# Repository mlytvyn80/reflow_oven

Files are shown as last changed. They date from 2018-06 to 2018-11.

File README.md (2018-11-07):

# Reflow owen

Description

## Getting Started

The firmware can be compiled using make utility. 
```
make all
```

Some more make targets are supported, namely *all, clean, coff extcodd program, debug.*
Please consult the Makefile for usage details.

### Prerequisites

In order to compile the HEX-file you need to install the AVR toolchain. 

In Ubuntu/Debian Linux this can be done using the following command:
```
sudo apt-get install gcc-avr
```

To be able to flash the firmware you will need a driver AVR MCU programmer (for example [usbasp](https://www.fischl.de/usbasp/) ) and the 
driving program like [avrdude](https://www.nongnu.org/avrdude/).

avrdude is included in the most of Linux distribution. In Ubuntu/Debian you can issue:
```
sudo apt-get install avrdude
```

### Flashing the firmware
Connect the ISP head with your AVR MCU programmer, programmer to PC and flash the compiled HEX-file:
```
avrdude -c usbasp -p m32u4 -U flash:w:ovencon.hex
```

In order to configure MCU to work with external oscillator (in our case 16MHz quartz), it is necessary to
setup fuse bits.

It can be done by command:
```
avrdude -c usbasp -p m32u4 -U hfuse:w:0xdd:m -U lfuse:w:0xde:m -U efuse:w:0xcf:m
```

## Built With

* [GNU AVR toolchain](http://www.dropwizard.io/1.0.2/docs/) - The web framework used
* [avrdude](https://maven.apache.org/) - Dependency Management
* [usbasp](https://www.fischl.de/usbasp/) - AVR MCU programmer

## Authors

* **Daniel Strother** - *Initial work* - [danstrother.com](https://danstrother.com/2011/01/15/reflow-oven-controller/)
* **Oleg Artamonov** - *PCB Design*  - [olegart.ru](http://olegart.ru/wordpress/reflow-soldering/)
* **Mykhailo Lytvyn** - Collect all necessary build-related information together.

## License

The code is distributed "AS IS" under original License by Dan Strother (see header comments in source code).

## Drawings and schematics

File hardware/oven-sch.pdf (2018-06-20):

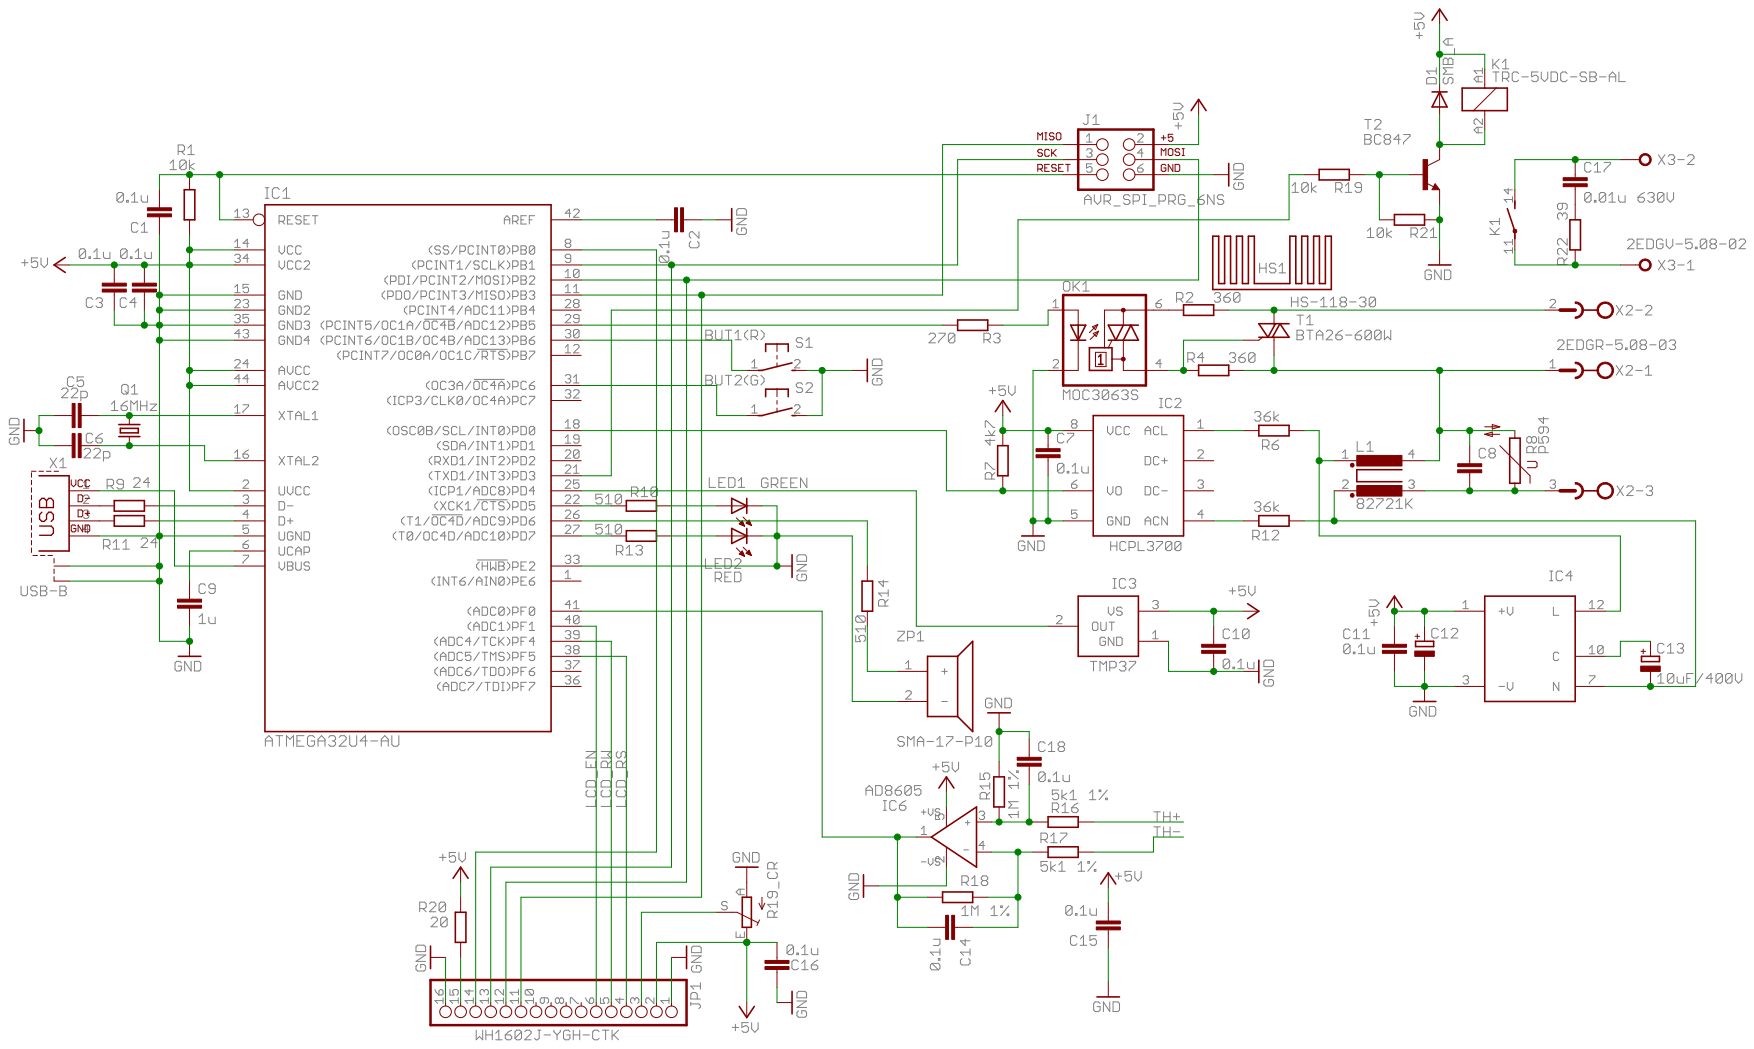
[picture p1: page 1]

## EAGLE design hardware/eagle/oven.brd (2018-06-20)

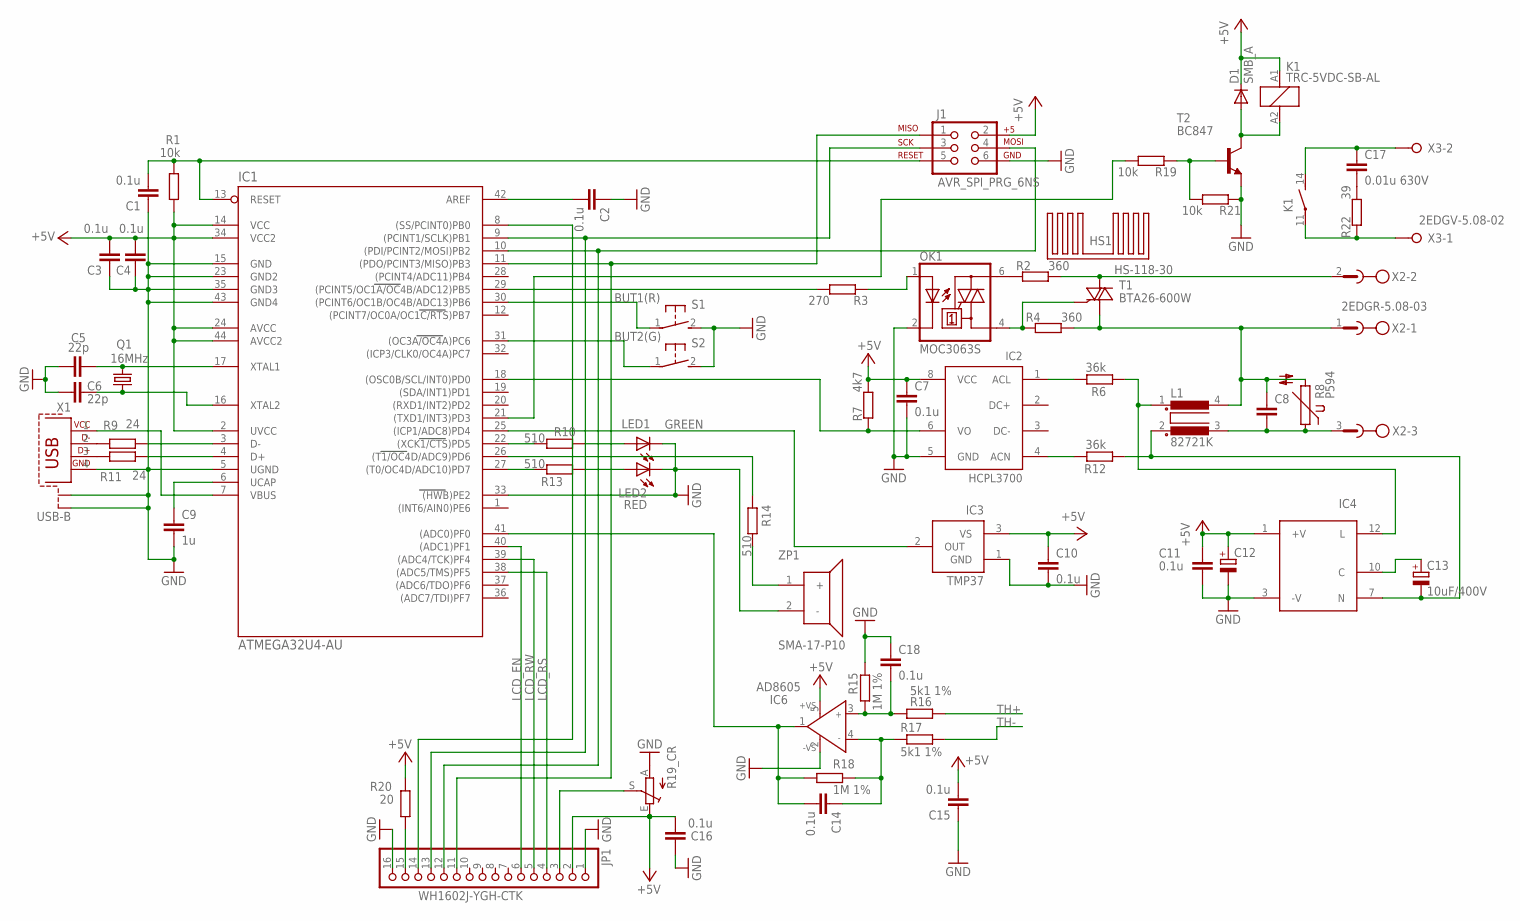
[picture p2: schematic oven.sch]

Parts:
C1, C2, C3, C4, C7, C10, C11, C14, C15, C16, C18: 0.1u; C0805R
C5, C6: 22p; C0805R
C8: C-EU102-054X133; C102-054X133
C9: 1u; C0805R
C12: CPOL-EUE3.5-8; E3,5-8
C13: 10uF/400V; E5-10,5
C17: 0.01u 630V; C102-043X133
D1: SMB_A; DO-214AC
HS1: HS-118-30; HS-118
IC1: ATMEGA32U4-AU; TQFP44
IC2: HCPL3700; DIL08
IC3: TMP37; TO92
IC4: PPM2.5-S12-05ELF; SIP12
IC6: AD8605; SOT23-5
J1: AVR_SPI_PRG_6NS; 2X3-NS
JP1: WH1602J-YGH-CTK; 1X16
K1: TRC-5VDC-SB-AL; TRC
L1: 82721K
LED1: GREEN; LED3MM
LED2: RED; LED3MM
OK1: MOC3063S; DIL6-SMD
Q1: 16MHz; HC49/S
R1, R19, R21: 10k; R0805R
R2, R4: 360; R2512
R3: 270; R0805R
R6, R12: 36k; R1206R
R7: 4k7; R0805R
R8: P594
R9, R11: 24; R0805R
R10, R13, R14: 510; R0805R
R15, R18: 1M 1%; R0805R
R16, R17: 5k1 1%; R0805R
R19_CR: TRIM_EU-CA6V; CA6V
R20: 20; R0805R
R22: 39; 0207/5V
S1, S2: 31-XX; B3F-31XX
T1: BTA26-600W; TOP3S-1
T2: BC847; SOT23
X1: USB-B; PN61729-S
X2: 2EDGR-5.08-03; W232-3
X3: 2EDGV-5.08-02; W237-132
ZP1: SMA-17-P10; SMA-17

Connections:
+5V: C3.2, C4.2, C7.1, C10.1, C11.1, C12.+, C15.2, C16.2, D1.C, IC1.2 (UVCC), IC1.14 (VCC), IC1.24 (AVCC), IC1.34 (VCC2), IC1.44 (AVCC2), IC2.8 (VCC), IC3.3 (VS), IC4.1 (+V), IC6.5 (+VS), J1.2, JP1.2, K1.A1 (1), R1.1, R7.2, R19_CR.E, R20.1
BUT1(R): IC1.30 ((PCINT6/OC1B/OC4B/ADC13)PB6), S1.1
BUT2(G): IC1.31 ((OC3A/OC4A)PC6), S2.1
GND: C1.1, C2.1, C3.1, C4.1, C5.1, C6.1, C7.2, C9.2, C10.2, C11.2, C12.-, C15.1, C16.1, C18.1, IC1.5 (UGND), IC1.15 (GND), IC1.23 (GND2), IC1.33 ((HWB)PE2), IC1.35 (GND3), IC1.43 (GND4), IC2.5 (GND), IC3.1 (GND), IC4.3 (-V), IC6.2 (-VS), J1.6, JP1.1, JP1.16, LED1.K (C), LED2.K (C), OK1.2 (C), R15.2, R19_CR.A, R21.1, S1.2 (S), S2.2 (S), T2.2 (E), X1.4, X1.S1, X1.S2, ZP1.2 (-)
LCD_D4: IC1.11 ((PDO/PCINT3/MISO)PB3), J1.1, JP1.11
LCD_D5: IC1.10 ((PDI/PCINT2/MOSI)PB2), J1.4, JP1.12
LCD_D6: IC1.9 ((PCINT1/SCLK)PB1), J1.3, JP1.13
LCD_D7: IC1.8 ((SS/PCINT0)PB0), JP1.14
LCD_EN: IC1.40 ((ADC1)PF1), JP1.6
LCD_RS: IC1.38 ((ADC5/TMS)PF5), JP1.4
LCD_RW: IC1.39 ((ADC4/TCK)PF4), JP1.5
unnamed: C9.1, IC1.6 (UCAP)
unnamed: R9.1, X1.2
unnamed: R11.1, X1.3
unnamed: IC1.3 (D-), R9.2
unnamed: IC1.4 (D+), R11.2
unnamed: IC1.7 (VBUS), X1.1
unnamed: IC1.18 ((OSC0B/SCL/INT0)PD0), IC2.6 (VO), R7.1
unnamed: C5.2, IC1.17 (XTAL1), Q1.2
unnamed: C6.2, IC1.16 (XTAL2), Q1.1
unnamed: IC1.29 ((PCINT5/OC1A/OC4B/ADC12)PB5), R3.2
unnamed: C1.2, IC1.13 (RESET), J1.5, R1.2
unnamed: C2.2, IC1.42 (AREF)
unnamed: C17.2, R22.2
unnamed: OK1.1 (A), R3.1
unnamed: OK1.6 (A2), R2.1
unnamed: OK1.4 (A1), R4.1, T1.G
unnamed: R2.2, T1.A2, X2.2
unnamed: IC4.12 (L), L1.1, R6.1
unnamed: JP1.15, R20.2
unnamed: IC1.25 ((ICP1/ADC8)PD4), IC3.2 (OUT)
unnamed: IC2.4 (ACN), R12.2
unnamed: C14.2, IC1.41 ((ADC0)PF0), IC6.1 (OUT), R18.1
unnamed: C18.2, IC6.3 (IN+), R15.1, R16.1
unnamed: C14.1, IC6.4 (IN-), R17.1, R18.2
unnamed: IC2.1 (ACL), R6.2
unnamed: LED1.A, R10.1
unnamed: C13.+, IC4.10 (C)
unnamed: IC1.22 ((XCK1/CTS)PD5), R10.2
unnamed: IC1.26 ((T1/OC4D/ADC9)PD6), R14.1
unnamed: IC1.27 ((T0/OC4D/ADC10)PD7), R13.2
unnamed: LED2.A, R13.1
unnamed: C13.-, IC4.7 (N), L1.2 (3), R12.1
unnamed: C8.1, L1.4 (2), R4.2, R8.2, T1.A1, X2.1
unnamed: C8.2, L1.3 (4), R8.1, X2.3
unnamed: JP1.3, R19_CR.S
unnamed: D1.A, K1.A2 (2), T2.3 (C)
unnamed: R19.1, R21.2, T2.1 (B)
unnamed: R14.2, ZP1.1 (+)
unnamed: C17.1, K1.14 (S), X3.2
unnamed: IC1.21 ((TXD1/INT3)PD3), R19.2
unnamed: K1.11, R22.1, X3.1
TH+: R16.2
TH-: R17.2

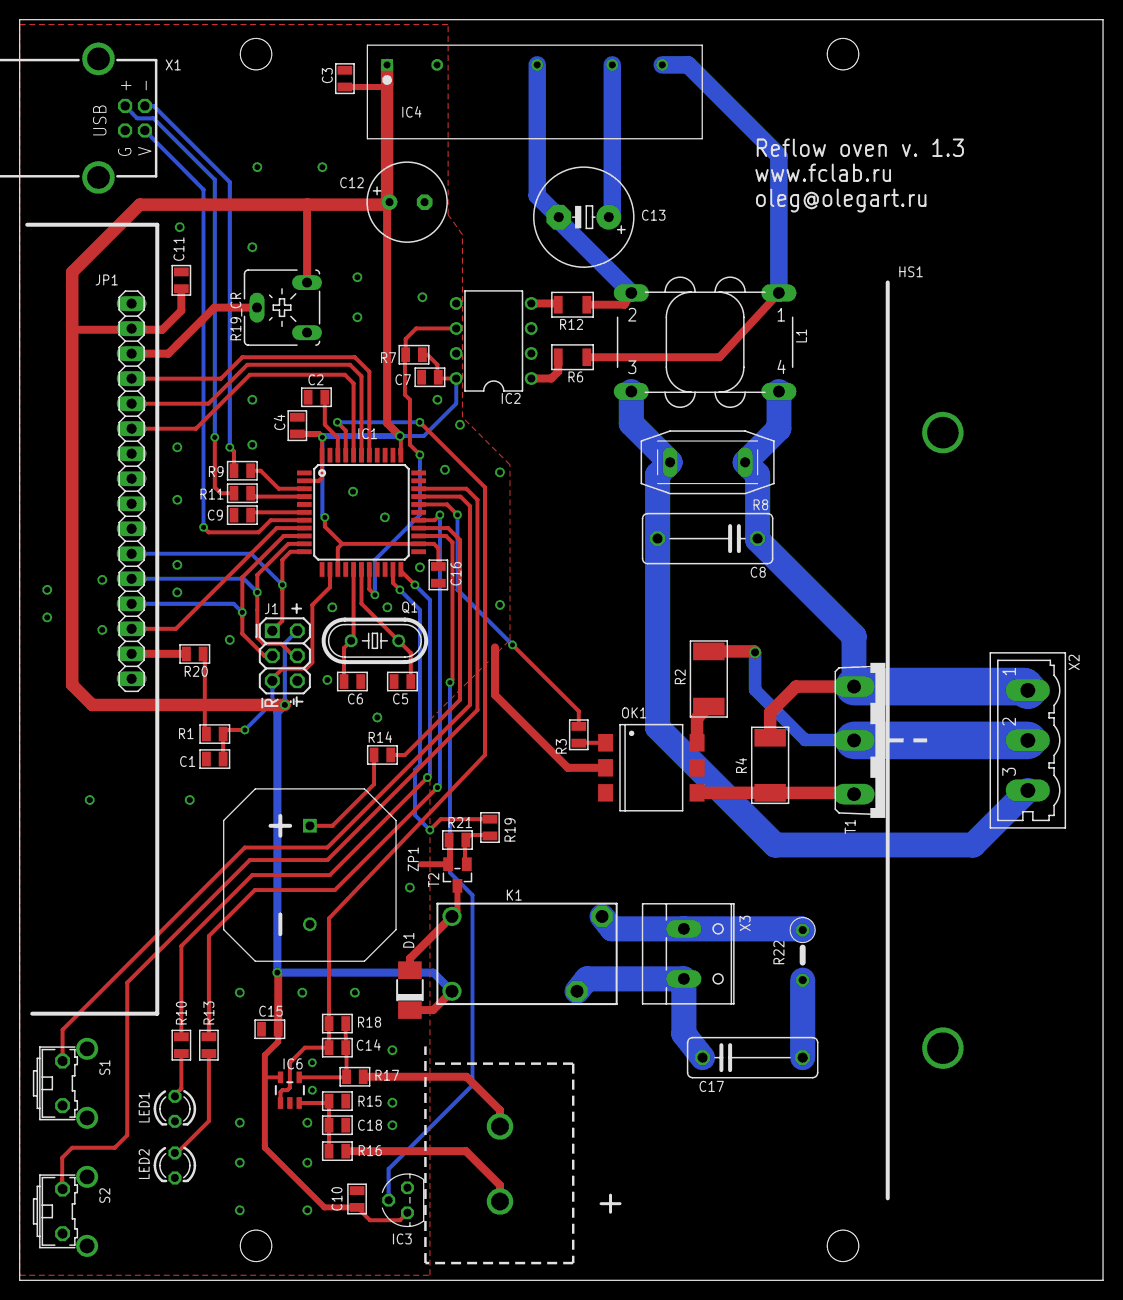
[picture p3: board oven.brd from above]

Board: 2 copper layers, 110.0 x 128.0 mm, 63 parts (0 on the bottom side), 52 nets.

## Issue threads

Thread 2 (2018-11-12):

Add udev rules

mlytvyn80, 2018-11-12:
Create udev rule file to setup correct rights to the device file.

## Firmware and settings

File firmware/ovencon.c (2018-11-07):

/**
 * Copyright (c) 2011, Daniel Strother < http://danstrother.com/ >
 * All rights reserved.
 *
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
 * THIS SOFTWARE IS PROVIDED BY THE AUTHOR "AS IS" AND ANY EXPRESS OR IMPLIED
 * WARRANTIES, INCLUDING, BUT NOT LIMITED TO, THE IMPLIED WARRANTIES OF
 * MERCHANTABILITY AND FITNESS FOR A PARTICULAR PURPOSE ARE DISCLAIMED. IN NO
 * EVENT SHALL THE AUTHOR BE LIABLE FOR ANY DIRECT, INDIRECT, INCIDENTAL,
 * SPECIAL, EXEMPLARY, OR CONSEQUENTIAL DAMAGES (INCLUDING, BUT NOT LIMITED
 * TO, PROCUREMENT OF SUBSTITUTE GOODS OR SERVICES; LOSS OF USE, DATA, OR
 * PROFITS; OR BUSINESS INTERRUPTION) HOWEVER CAUSED AND ON ANY THEORY OF
 * LIABILITY, WHETHER IN CONTRACT, STRICT LIABILITY, OR TORT (INCLUDING
 * NEGLIGENCE OR OTHERWISE) ARISING IN ANY WAY OUT OF THE USE OF THIS
 * SOFTWARE, EVEN IF ADVISED OF THE POSSIBILITY OF SUCH DAMAGE.
 */

/**
  * Modified by Oleg Artamonov
  * Modified by Mykhailo Lytvyn
 */

#define VERSION "2012-08-11/1"

#include <avr/io.h>
#include <avr/interrupt.h>
#include <avr/pgmspace.h>
#include <avr/wdt.h>
#include <util/delay.h>
#include <stdint.h>
#include <string.h>
#include <stdio.h>

#include "usb_serial.h"

#include "oven_ssr.h"
#include "oven_timing.h"
#include "oven_pid.h"
#include "oven_profile.h"
#include "thcouple.h"
#include "lcd.h"

#define gled_on() PORTD |= _BV(5)
#define gled_off() PORTD &= ~_BV(5)
#define buzzer_on() PORTD |= _BV(6)
#define buzzer_off() PORTD &= ~_BV(6)
#define rled_on() PORTD |= _BV(7)
#define rled_off() PORTD &= ~_BV(7)
#define relay_on() PORTD |= _BV(3)
#define relay_off() PORTD &= ~_BV(3)

#define button1() !(PINB & (1<<PB6))
#define button2() !(PINC & (1<<PC6))

uint32_t Boot_Key __attribute__ ((section (".noinit")));
#define MAGIC_BOOT_KEY            0xDC42ACCA
#define BOOTLOADER_START_ADDRESS  0x7000

void Jump_To_Bootloader(void)
{
    // Disable all interrupts
    cli();

    // Set the bootloader key to the magic value and force a reset
    Boot_Key = MAGIC_BOOT_KEY;
    wdt_enable(WDTO_250MS);
    for (;;);
}


volatile uint8_t mode_manual;
volatile int16_t manual_target;
volatile uint8_t manual_target_changed;


#define CMD_RESET   1
#define CMD_GO      2
#define CMD_PAUSE   3
#define CMD_RESUME  4
#define CMD_MANUAL  5

// TODO: currently, only one comm_cmd can be processed per oven_update_4hz
// invocation, so multiple commands received within a ~0.25s window may be lost
volatile uint8_t comm_cmd;


// controller state

#define ST_FAULT    0
#define ST_IDLE     1
#define ST_RUN      2
#define ST_DONE     3
#define ST_PAUSE    4
#define ST_MANUAL   5

const char *state_names[6] = { "Fault", "Idle", "Run", "Done", "Pause", "Manual" };

uint8_t state = ST_FAULT;

int16_t target;
uint16_t time;
uint8_t buzzer;
uint8_t fw_update;

volatile uint8_t lcd_update_now;
volatile uint8_t button_pressed;
volatile uint8_t profile_num;

void fault(void)
{
    state = ST_FAULT;
    ssr_fault();
}

void oven_output(uint8_t heater)
{
    ssr_set(heater);
}

void oven_input(int16_t *heater)
{
    *heater = thcouple_read();
}

void oven_setup(void)
{
    state = ST_IDLE;

    mode_manual	= 0;
    manual_target_changed = 0;
    comm_cmd = 0;
    target = 0;
    time = 0;
    buzzer = 0;
    fw_update  = 0;


    lcd_update_now = 0;
    button_pressed = 0;
    profile_num = 0;

    pid_reset();
    profile_reset(0);
    ssr_setup();
    adc_setup();
    timing_setup(); // timing setup last, since it enables timer interrupts (which invoke the update functions below)
}

void oven_update_120hz(void)
{
    ssr_update();

    // process buttons

    if (!button_pressed)
    {
        if (button1()) // button 1 (red) pressed
        {
            button_pressed = 1;
            switch (state)
            {
                case ST_FAULT:
                    mode_manual = 0;
                    comm_cmd = CMD_RESET;
                    break;
                case ST_IDLE:
                    if (!mode_manual)
                        comm_cmd = CMD_GO;
                    else
                        comm_cmd = CMD_MANUAL;

                    if (fw_update)
                    {
                        lcd_put_two_rows("FIRMWARE UPDATE", "Atmel FLIP v/USB");
                        usb_serial_flush_output();
                        Jump_To_Bootloader();
                    }
                    break;
                case ST_RUN:
                    comm_cmd = CMD_PAUSE;
                    break;
                case ST_DONE:
                    comm_cmd = CMD_RESET;
                    break;
                case ST_PAUSE:
                    comm_cmd = CMD_RESET;
                    break;
                case ST_MANUAL:
                    if (!manual_target_changed)
                    {
                        comm_cmd = CMD_PAUSE;
                    }
                    else
                    {
                        target = manual_target;
                        manual_target_changed = 0;
                    }
                    break;
                default:
                    break;
            }
            lcd_update_now = 1;
        }

        if (button2()) // button 2 (green) pressed
        {
            button_pressed = 1;
            switch (state)
            {
                case ST_FAULT:
                    break;
                case ST_IDLE:
                    profile_num++;
                    mode_manual = 0;
                    fw_update = 0;

                    if (profile_num == (PROFILES+2))
                        profile_num = 0;

                    if (profile_num < PROFILES)
                        profile_reset(profile_num);

                    if (profile_num == PROFILES)
                    {
                        mode_manual = 1;
                        manual_target = 200; // 50 *C
                    }

                    if (profile_num == PROFILES+1)
                    {
                        fw_update = 1;
                    }
                    break;
                case ST_RUN:
                    break;
                case ST_DONE:
                    break;
                case ST_PAUSE:
                    comm_cmd = CMD_RESUME;
                    break;
                case ST_MANUAL:
                    manual_target += 20;
                    if (manual_target > 1000) // 250 *C
                        manual_target = 200; // 50 *C
                    manual_target_changed = 1;
                    break;
                default:
                    break;
            }
            lcd_update_now = 1;
        }
    }
    else
    {
        if ( button2() && (state == ST_MANUAL) ) // button 2 (green) still pressed, manual mode
        {
            button_pressed++;
            if (button_pressed > 59)
                button_pressed = 0;
        }

        if ( !(button1() | button2()) ) // no button pressed
        {
            button_pressed++;
            if (button_pressed > 10)
                button_pressed = 0;
        }
    }
}

char tx_msg[255];
volatile uint8_t tx_len = 0;
volatile uint8_t lcd_update_1hz = 0;
volatile uint8_t led_blink = 0;

void oven_update_4hz(void)
{
    int16_t temp;
    uint8_t step;
    uint16_t time;

    oven_input(&temp);

    if(comm_cmd != 0)
    {
        switch(comm_cmd)
        {
            case CMD_RESET:
                profile_reset(0);
                pid_reset();
                state = ST_IDLE;
                mode_manual = 0;
                target = 0;
                profile_num = 0;
                break;
            case CMD_GO:
                if(state == ST_IDLE) {
                    state = ST_RUN;
                }
                break;
            case CMD_PAUSE:
                if((state == ST_RUN) || (state == ST_MANUAL)) {
                    state = ST_PAUSE;
                }
                break;
            case CMD_RESUME:
                if(state == ST_PAUSE) {
                    if (!mode_manual)
                        state = ST_RUN;
                    else
                        state = ST_MANUAL;
                }
                break;
            case CMD_MANUAL:
                if (state == ST_IDLE) {
                    target		= manual_target;
                    state		= ST_MANUAL;
                }
                break;
            default:
                fault();
        }

        comm_cmd = 0;
    }

    switch(state)
    {
        case ST_IDLE:
            rled_off();
            relay_off();
            break;
        case ST_RUN:
            rled_on();
            if(profile_update(&target, &step, &time, &buzzer))
            {
                state = ST_DONE;
                buzzer = 8;
            }
            if ((target - temp) > 100) // 25 *C difference
                fault();
            break;
        case ST_PAUSE:
            rled_on();
            // hold target
            break;
        case ST_DONE:
            rled_off();
            relay_off();
            target = 0;
            break;
        case ST_FAULT:
            if (led_blink)
            {
                rled_off();
                led_blink = 0;
            }
            else
            {
                rled_on();
                led_blink = 1;
            }
            break;
        case ST_MANUAL:
            rled_on();
            break;
        default:
            fault();
    }

    oven_output(pid_update(temp, target));

    lcd_update_1hz++;
    char lcd_str[16];
    char lcd_degree = 0xDF;

    if ((lcd_update_1hz == 4) || (lcd_update_now))
    {
        if (buzzer != 0)
        {
            if (buzzer % 2 == 0)
                buzzer_on();
            else
                buzzer_off();

            buzzer--;

            relay_on();
        }

        lcd_clrscr();

        sprintf_P(lcd_str, PSTR("%s %d%cC"), state_names[state], temp>>2, lcd_degree);

        lcd_puts(lcd_str);

        lcd_gotoxy(0, 1);

        if (state == ST_RUN)
        {
            //	2/7 150 s 540 *C -- step, time until next step, target temperature
            sprintf_P(lcd_str, PSTR("%d/%d %ds %d%cC"), step, STEPS, time, target>>2, lcd_degree);
            lcd_puts(lcd_str);
        }

        if (state == ST_MANUAL)
        {
            if (!manual_target_changed)
                sprintf_P(lcd_str, PSTR("Target: %d%cC"), target>>2, lcd_degree);
            else
                sprintf_P(lcd_str, PSTR("%d%cC->%d%cC?"), target>>2, lcd_degree, manual_target>>2, lcd_degree);

            lcd_puts(lcd_str);
        }

        if (state == ST_IDLE)
        {
            switch (profile_num)
            {
                case 0:		//0123456789ABCDEF
                    lcd_puts("1.Lead (fast)");
                    break;
                case 1:
                    lcd_puts("2.Lead (slow)");
                    break;
                case 2:
                    lcd_puts("3.Lead-free");
                    break;
                case 3:
                    lcd_puts("4.Manual control");
                    break;
                case 4:
                    lcd_puts("5.USB F/W update");
                    break;
                default:
                    lcd_puts("UNKNOWN PROFILE");
                    break;
            }
        }

        if (state == ST_FAULT)
        {
            sprintf_P(lcd_str, PSTR("TG%d%cC T%d%cC"), target>>2, lcd_degree, temp>>2, lcd_degree);
            
            lcd_put_two_rows("CHECK TH.COUPLE!", lcd_str);                        
        }

        if (state == ST_PAUSE)
        {
            lcd_puts("1 stop, 2 resume");
        }

        lcd_update_1hz = 0;
        lcd_update_now = 0;
    }

    time++;
}

char rx_msg[255];
uint8_t rx_cnt;

void process_message(const char *msg)
{
    // this is a ridiculously expensive function to invoke - a more efficient
    // command parser could be implemented, or a binary protocol established -
    // but, we're not expecting a lot of command traffic in this application,
    // and all of the timing-critical routines are handled by interrupts, so
    // there isn't a lot of downside to this expensive-but-easy implementation

    uint16_t eeprom_data;
    char response[50];
    uint8_t resplen;

    if(strcmp_P(msg,PSTR("reset")) == 0) {
        comm_cmd = CMD_RESET;
    } else if(strcmp_P(msg,PSTR("go")) == 0) {
        comm_cmd = CMD_GO;
    } else if(strcmp_P(msg,PSTR("pause")) == 0) {
        comm_cmd = CMD_PAUSE;
    } else if(strcmp_P(msg,PSTR("resume")) == 0) {
        comm_cmd = CMD_RESUME;
    } else if(strcmp_P(msg,PSTR("update")) == 0) { // update firmware via USB        
        lcd_put_two_rows("FIRMWARE UPDATE", "RESTART TO ABORT");
        usb_serial_write((void*)"* Update firmware with Atmel FLIP", 33);
        usb_serial_flush_output();
        Jump_To_Bootloader();
    } else if(sscanf_P(msg,PSTR("coeff: %d"), &eeprom_data)) { // TH couple correction coefficient, default 31
        set_coeff(eeprom_data);
        resplen = sprintf_P(response, PSTR("* Coeff: %d\n"), th_coeff);
        usb_serial_write((void*)response, resplen);
    } else if(sscanf_P(msg,PSTR("shift: %d"), &eeprom_data)) { // TMP37 cold junction zero shift, default 0
        set_zero(eeprom_data);
        resplen = sprintf_P(response, PSTR("* Shift: %d\n"), zero_shift);
        usb_serial_write((void*)response, resplen);
    } else if(strcmp_P(msg,PSTR("coeff?")) == 0) {
        resplen = sprintf_P(response, PSTR("* Coeff: %d\n"), th_coeff);
        usb_serial_write((void*)response, resplen);
    } else if(strcmp_P(msg,PSTR("shift?")) == 0) {
        resplen = sprintf_P(response, PSTR("* Shift: %d\n"), zero_shift);
        usb_serial_write((void*)response, resplen);
    }
}

void avr_init(void)
{
    // If the reset source was the bootloader and the key is correct, clear it and jump to the bootloader
    if ((MCUSR & (1<<WDRF)) && (Boot_Key == MAGIC_BOOT_KEY))
    {
        Boot_Key = 0;
        ((void (*)(void))BOOTLOADER_START_ADDRESS)();
    }

    SPCR &= ~(1<<SPE);

    // Pullups
    PINB |= (1<<PB6);
    PINC |= (1<<PC6)|(1<<PC7);
    
    // LED status lights
    DDRD |= (1<<PD5)|(1<<PD6)|(1<<PD7);
    DDRD |= (1<<PD3);
    
    rled_on();
    relay_off();
    
    usb_init();
}

void show_greetings_msg(void)
{
    lcd_clrscr();

    lcd_put_two_rows_animate("REFLOW  OVEN", " CONTROLLER ");
    _delay_ms(500);
    
    lcd_put_two_rows_animate("Mykhailo Lytvyn", "   lytvyn.at   ");
    _delay_ms(500);

    lcd_put_two_rows("FIRMWARE VERSION", VERSION);

}

// program entry point
int main(void)
{
    avr_init();
    
    lcd_init(LCD_DISP_ON);
    
    show_greetings_msg();
    
    oven_setup();

    // wait an arbitrary bit for the host to complete its side of the init
    _delay_ms(1000);

    // clear any stale packets
    usb_serial_flush_input();

    rled_off();
    gled_on();
    
    rx_cnt = 0;

    int8_t ret;
    while(1)
    {
        // receive individual characters from the host
        while( (ret = usb_serial_getchar()) != -1)
        {
            // all commands are terminated with a new-line
            if(ret == '\n') 
            {
                // only process commands that haven't overflowed the buffer
                if(rx_cnt > 0 && rx_cnt < 255) 
                {
                    rx_msg[rx_cnt] = '\0';
                    process_message(rx_msg);
                }
                rx_cnt = 0;
            } else {
                // buffer received characters
                rx_msg[rx_cnt] = ret;
                if(rx_cnt != 255) rx_cnt++;
            }
        }
    }
}

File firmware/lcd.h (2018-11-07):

#ifndef LCD_H
#define LCD_H
/*************************************************************************
 Title	:   C include file for the HD44780U LCD library (lcd.c)
 Author:    Peter Fleury <pfleury@gmx.ch>  http://jump.to/fleury
 File:	    $Id: lcd.h,v 1.13.2.2 2006/01/30 19:51:33 peter Exp $
 Software:  AVR-GCC 3.3
 Hardware:  any AVR device, memory mapped mode only for AT90S4414/8515/Mega
***************************************************************************/

/**
 @defgroup pfleury_lcd LCD library
 @code #include <lcd.h> @endcode
 
 @brief Basic routines for interfacing a HD44780U-based text LCD display

 Originally based on Volker Oth's LCD library,
 changed lcd_init(), added additional constants for lcd_command(), 
 added 4-bit I/O mode, improved and optimized code.
       
 Library can be operated in memory mapped mode (LCD_IO_MODE=0) or in 
 4-bit IO port mode (LCD_IO_MODE=1). 8-bit IO port mode not supported.

 Memory mapped mode compatible with Kanda STK200, but supports also 
 generation of R/W signal through A8 address line.
       
 @author Peter Fleury pfleury@gmx.ch http://jump.to/fleury
 
 @see The chapter <a href="http://homepage.sunrise.ch/mysunrise/peterfleury/avr-lcd44780.html" target="_blank">Interfacing a HD44780 Based LCD to an AVR</a>
      on my home page.

*/

/*@{*/

#if (__GNUC__ * 100 + __GNUC_MINOR__) < 303
#error "This library requires AVR-GCC 3.3 or later, update to newer AVR-GCC compiler !"
#endif

#include <inttypes.h>
#include <avr/pgmspace.h>

/** 
 *  @name  Definitions for MCU Clock Frequency
 *  Adapt the MCU clock frequency in Hz to your target. 
 */
#define XTAL 16000000              /**< clock frequency in Hz, used to calculate delay timer */


/**
 * @name  Definition for LCD controller type
 * Use 0 for HD44780 controller, change to 1 for displays with KS0073 controller.
 */
#define LCD_CONTROLLER_KS0073 0  /**< Use 0 for HD44780 controller, 1 for KS0073 controller */

/** 
 *  @name  Definitions for Display Size 
 *  Change these definitions to adapt setting to your display
 */
#define LCD_LINES           2     /**< number of visible lines of the display */
#define LCD_DISP_LENGTH    16     /**< visibles characters per line of the display */
#define LCD_LINE_LENGTH  0x40     /**< internal line length of the display    */
#define LCD_START_LINE1  0x00     /**< DDRAM address of first char of line 1 */
#define LCD_START_LINE2  0x40     /**< DDRAM address of first char of line 2 */
#define LCD_START_LINE3  0x14     /**< DDRAM address of first char of line 3 */
#define LCD_START_LINE4  0x54     /**< DDRAM address of first char of line 4 */
#define LCD_WRAP_LINES      0     /**< 0: no wrap, 1: wrap at end of visibile line */


#define LCD_IO_MODE      1         /**< 0: memory mapped mode, 1: IO port mode */
#if LCD_IO_MODE
/**
 *  @name Definitions for 4-bit IO mode
 *  Change LCD_PORT if you want to use a different port for the LCD pins.
 *
 *  The four LCD data lines and the three control lines RS, RW, E can be on the 
 *  same port or on different ports. 
 *  Change LCD_RS_PORT, LCD_RW_PORT, LCD_E_PORT if you want the control lines on
 *  different ports. 
 *
 *  Normally the four data lines should be mapped to bit 0..3 on one port, but it
 *  is possible to connect these data lines in different order or even on different
 *  ports by adapting the LCD_DATAx_PORT and LCD_DATAx_PIN definitions.
 *  
 */
#define LCD_PORT         PORTB        /**< port for the LCD lines   */
#define LCD_DATA0_PORT   LCD_PORT     /**< port for 4bit data bit 0 */
#define LCD_DATA1_PORT   LCD_PORT     /**< port for 4bit data bit 1 */
#define LCD_DATA2_PORT   LCD_PORT     /**< port for 4bit data bit 2 */
#define LCD_DATA3_PORT   LCD_PORT     /**< port for 4bit data bit 3 */
#define LCD_DATA0_PIN    3            /**< pin for 4bit data bit 0  */
#define LCD_DATA1_PIN    2            /**< pin for 4bit data bit 1  */
#define LCD_DATA2_PIN    1            /**< pin for 4bit data bit 2  */
#define LCD_DATA3_PIN    0            /**< pin for 4bit data bit 3  */
#define LCD_RS_PORT      PORTF        /**< port for RS line         */
#define LCD_RS_PIN       5            /**< pin  for RS line         */
#define LCD_RW_PORT      PORTF        /**< port for RW line         */
#define LCD_RW_PIN       4            /**< pin  for RW line         */
#define LCD_E_PORT       PORTF     /**< port for Enable line     */
#define LCD_E_PIN        1            /**< pin  for Enable line     */

#elif defined(__AVR_AT90S4414__) || defined(__AVR_AT90S8515__) || defined(__AVR_ATmega64__) || \
      defined(__AVR_ATmega8515__)|| defined(__AVR_ATmega103__) || defined(__AVR_ATmega128__) || \
      defined(__AVR_ATmega161__) || defined(__AVR_ATmega162__)
/*
 *  memory mapped mode is only supported when the device has an external data memory interface
 */
#define LCD_IO_DATA      0xC000    /* A15=E=1, A14=RS=1                 */
#define LCD_IO_FUNCTION  0x8000    /* A15=E=1, A14=RS=0                 */
#define LCD_IO_READ      0x0100    /* A8 =R/W=1 (R/W: 1=Read, 0=Write   */
#else
#error "external data memory interface not available for this device, use 4-bit IO port mode"

#endif


/**
 *  @name Definitions for LCD command instructions
 *  The constants define the various LCD controller instructions which can be passed to the 
 *  function lcd_command(), see HD44780 data sheet for a complete description.
 */

/* instruction register bit positions, see HD44780U data sheet */
#define LCD_CLR               0      /* DB0: clear display                  */
#define LCD_HOME              1      /* DB1: return to home position        */
#define LCD_ENTRY_MODE        2      /* DB2: set entry mode                 */
#define LCD_ENTRY_INC         1      /*   DB1: 1=increment, 0=decrement     */
#define LCD_ENTRY_SHIFT       0      /*   DB2: 1=display shift on           */
#define LCD_ON                3      /* DB3: turn lcd/cursor on             */
#define LCD_ON_DISPLAY        2      /*   DB2: turn display on              */
#define LCD_ON_CURSOR         1      /*   DB1: turn cursor on               */
#define LCD_ON_BLINK          0      /*     DB0: blinking cursor ?          */
#define LCD_MOVE              4      /* DB4: move cursor/display            */
#define LCD_MOVE_DISP         3      /*   DB3: move display (0-> cursor) ?  */
#define LCD_MOVE_RIGHT        2      /*   DB2: move right (0-> left) ?      */
#define LCD_FUNCTION          5      /* DB5: function set                   */
#define LCD_FUNCTION_8BIT     4      /*   DB4: set 8BIT mode (0->4BIT mode) */
#define LCD_FUNCTION_2LINES   3      /*   DB3: two lines (0->one line)      */
#define LCD_FUNCTION_10DOTS   2      /*   DB2: 5x10 font (0->5x7 font)      */
#define LCD_CGRAM             6      /* DB6: set CG RAM address             */
#define LCD_DDRAM             7      /* DB7: set DD RAM address             */
#define LCD_BUSY              7      /* DB7: LCD is busy                    */
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
